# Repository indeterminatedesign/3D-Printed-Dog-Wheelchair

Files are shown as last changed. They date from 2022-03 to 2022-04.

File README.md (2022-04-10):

<h1>3D Printed Dog Wheelchair</h1>
<p>The construction is a bit unrefined given this was a version 1, and as such is not beginner project as it requires intermediate fabrication skills at a minimum. 
Feel free to take this design to the next level for your purposes. </p>
<p>The wheelchair is made from mostly 3d printed parts and uses 1/2" EMT conduit for its main structure. I've tested the wheelchair with a 65lbs dog and found no issues, but obviously your mileage may vary. </p>

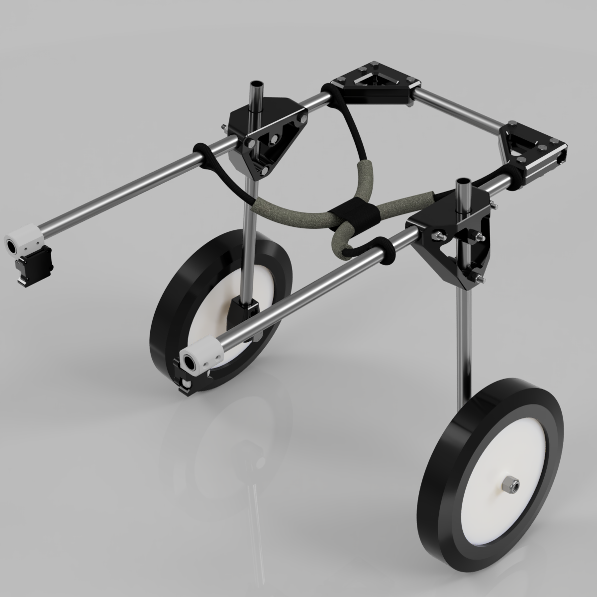
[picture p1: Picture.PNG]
Wheelchair Picture


<h2>Materials List</h2>
<p>You'll of course need a full assortment of the appropriate tools, including wrenches, hacksaw/tubing cutter, drill, drill bits, zip ties, electrical tape, etc.  </p>
<p>Depending on your dog's size it's typically cheaper to buy a single 10' length piece of conduit.  </p>

<p>The 3D printed structure of wheelchair can be printed out of PLA, PLA+ (Highly recommended) or PETG.  I highly recommend PETG or Nylon for the buckles as it is more durable, easier to unbuckle, and holds it shape better than PLA.  The 3D printed parts require roughly 0.8kg of filament.</p>

<p>The wheels I used are cheap 10" cart wheels from Harbor Freight, but any 1/2" diameter axle wheel can be used.  Obviously the larger the diameter the easier the wheelchair can traverse obstacles.</p>

The sling is made from vinyl tubing with a 1/4" ID, (I used some unknown tubing that I already had so this may not be the exact size).  I purchased 10mm ID, EVA foam tube padding from Amazon. 
To create the middle of the sling I use a hiking sock cut in half.  Obviously, this could be improved.</p>
<p>Additionally, you'll need a harness that fits your dog to clamp the buckle brackets to.  This is the harness I used: https://www.amazon.com/tobeDRI-Harness-Adjustable-Reflective-Control/dp/B086PCQ3HQ/?th=1</p>

<h4>Hardware List</h4>
<meta http-equiv="Content-Type" content="text/html; charset=utf-8"><link type="text/css" rel="stylesheet" href="resources/sheet.css" >
<div class="ritz grid-container" dir="ltr"><table class="waffle" cellspacing="0" cellpadding="0"><thead><tr><th class="row-header freezebar-origin-ltr"></th><th id="0C0" style="width:96px;" class="column-headers-background">A</th><th id="0C1" style="width:100px;" class="column-headers-background">B</th><th id="0C2" style="width:40px;" class="column-headers-background">C</th><th id="0C3" style="width:134px;" class="column-headers-background">D</th></tr></thead><tbody><tr style="height: 20px"><th id="0R0" style="height: 20px;" class="row-headers-background"><div class="row-header-wrapper" style="line-height: 20px">1</div></th><td class="s0" dir="ltr">Bolt</td><td class="s0" dir="ltr">Length</td><td class="s0" dir="ltr">Qty.</td><td class="s1 softmerge" dir="ltr"><div class="softmerge-inner" style="width:232px;left:-1px">Optional Metric Size</div></td></tr><tr style="height: 20px"><th id="0R1" style="height: 20px;" class="row-headers-background"><div class="row-header-wrapper" style="line-height: 20px">2</div></th><td class="s2" dir="ltr">1/4-20</td><td class="s2" dir="ltr">1.5&quot;</td><td class="s3" dir="ltr">10</td><td class="s4" dir="ltr">M6x40</td></tr><tr style="height: 20px"><th id="0R2" style="height: 20px;" class="row-headers-background"><div class="row-header-wrapper" style="line-height: 20px">3</div></th><td class="s5" dir="ltr">1/4-20</td><td class="s5" dir="ltr">2&quot;</td><td class="s6" dir="ltr">6</td><td class="s7" dir="ltr">M6x50</td></tr><tr style="height: 20px"><th id="0R3" style="height: 20px;" class="row-headers-background"><div class="row-header-wrapper" style="line-height: 20px">4</div></th><td class="s2" dir="ltr">1/4-20</td><td class="s2" dir="ltr">2.5&quot;</td><td class="s3" dir="ltr">2</td><td class="s4" dir="ltr">M6x65</td></tr><tr style="height: 20px"><th id="0R4" style="height: 20px;" class="row-headers-background"><div class="row-header-wrapper" style="line-height: 20px">5</div></th><td class="s5" dir="ltr">1/4-20 Locnuts</td><td class="s5"></td><td class="s6" dir="ltr">18</td><td class="s7" dir="ltr">M6</td></tr><tr style="height: 20px"><th id="0R5" style="height: 20px;" class="row-headers-background"><div class="row-header-wrapper" style="line-height: 20px">6</div></th><td class="s2" dir="ltr">1/4&quot; Washers</td><td class="s2" dir="ltr"></td><td class="s3" dir="ltr">36</td><td class="s4" dir="ltr">M6</td></tr><tr style="height: 20px"><th id="0R6" style="height: 20px;" class="row-headers-background"><div class="row-header-wrapper" style="line-height: 20px">7</div></th><td class="s5" dir="ltr">1/2&quot;</td><td class="s5" dir="ltr">4.25&quot;-4.5&quot;</td><td class="s6" dir="ltr">2</td><td class="s7" dir="ltr">M13x110</td></tr><tr style="height: 20px"><th id="0R7" style="height: 20px;" class="row-headers-background"><div class="row-header-wrapper" style="line-height: 20px">8</div></th><td class="s2" dir="ltr">1/2&quot; Locnuts</td><td class="s2"></td><td class="s3" dir="ltr">2</td><td class="s4" dir="ltr">M13</td></tr><tr style="height: 20px"><th id="0R8" style="height: 20px;" class="row-headers-background"><div class="row-header-wrapper" style="line-height: 20px">9</div></th><td class="s5" dir="ltr">1/2&quot; Washers</td><td class="s5" dir="ltr"></td><td class="s6" dir="ltr">4</td><td class="s7" dir="ltr">M13</td></tr><tr style="height: 20px"><th id="0R9" style="height: 20px;" class="row-headers-background"><div class="row-header-wrapper" style="line-height: 20px">10</div></th><td class="s2 softmerge" dir="ltr"><div class="softmerge-inner" style="width:93px;left:-1px">#8-32 flat head</div></td><td class="s2" dir="ltr">~5/8&quot;</td><td class="s3" dir="ltr">4</td><td class="s4" dir="ltr">M4x13 flat head</td></tr><tr style="height: 20px"><th id="0R10" style="height: 20px;" class="row-headers-background"><div class="row-header-wrapper" style="line-height: 20px">11</div></th><td class="s5 softmerge" dir="ltr"><div class="softmerge-inner" style="width:93px;left:-1px">#8-32 flat head</div></td><td class="s5" dir="ltr">~1 1/8&quot;</td><td class="s6" dir="ltr">4</td><td class="s7" dir="ltr">M4x30 flat head</td></tr></tbody></table></div>
<i>Note:  Washers are absolutely critical as they help to distribute the load over a larger area.</i>

<h2>Printing Instructions</h2>
<p>Most of the parts can be printed without supports, and I highly recommend doing so.  
The parts that I know require support are the large triangular upper block pieces.</p>
<p> I printed all of my parts with 5 walls and 5 top and bottom layers with 30% infill.   

<h2>Assembly Instructions</h2>
See my YouTube video below.

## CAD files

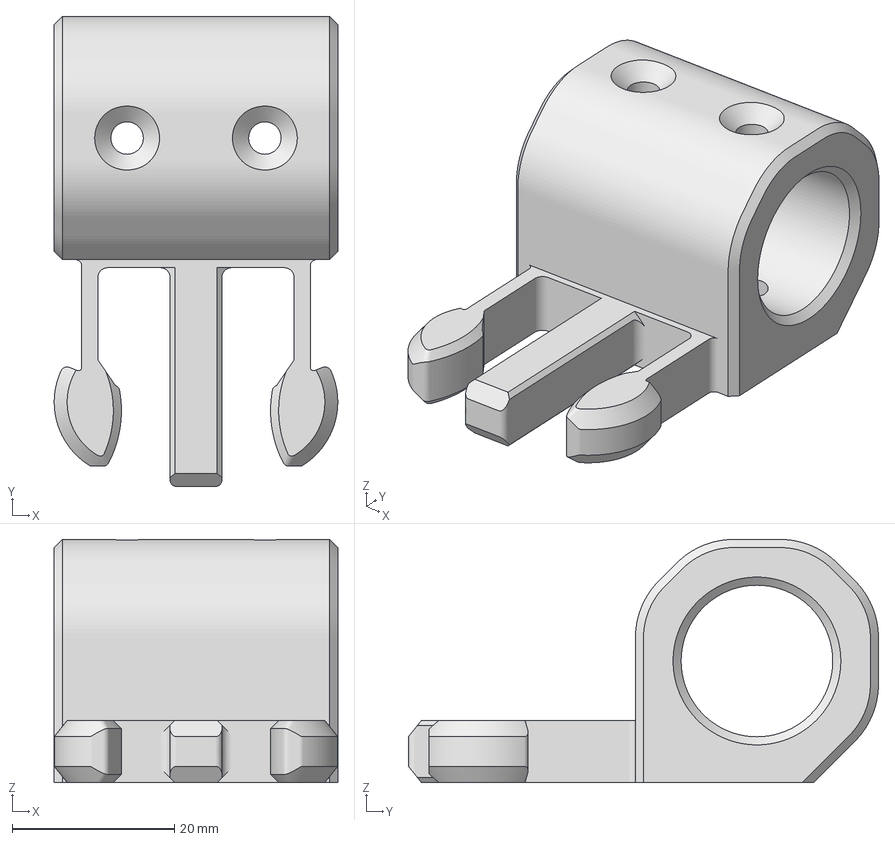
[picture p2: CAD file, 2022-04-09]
3MF Files/Front Buckle Frame Side.3mf
35.0 x 58.0 x 30.0 mm

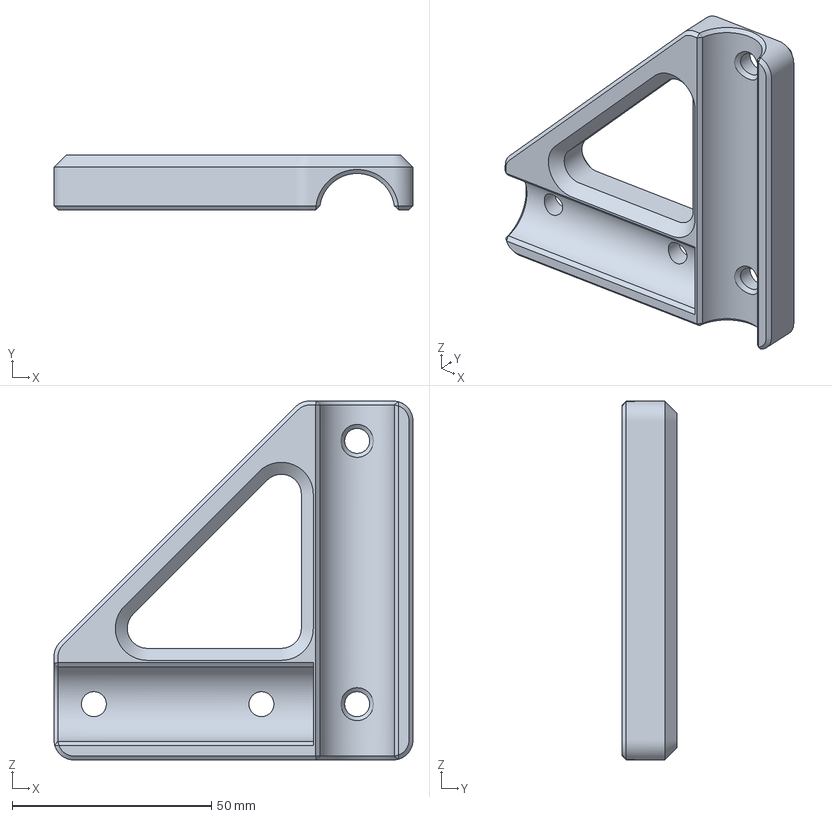
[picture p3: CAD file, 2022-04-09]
3MF Files/2x RightAngle Connector(Mirror).3mf
90.0 x 13.7 x 90.0 mm

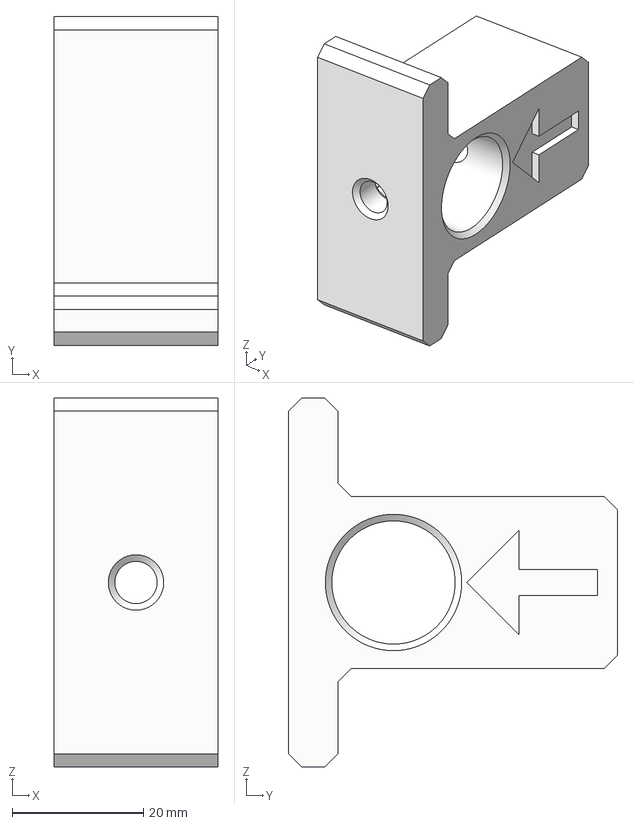
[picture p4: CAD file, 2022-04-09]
3MF Files/HoleDrillJig.3mf
25.0 x 50.2 x 56.3 mm

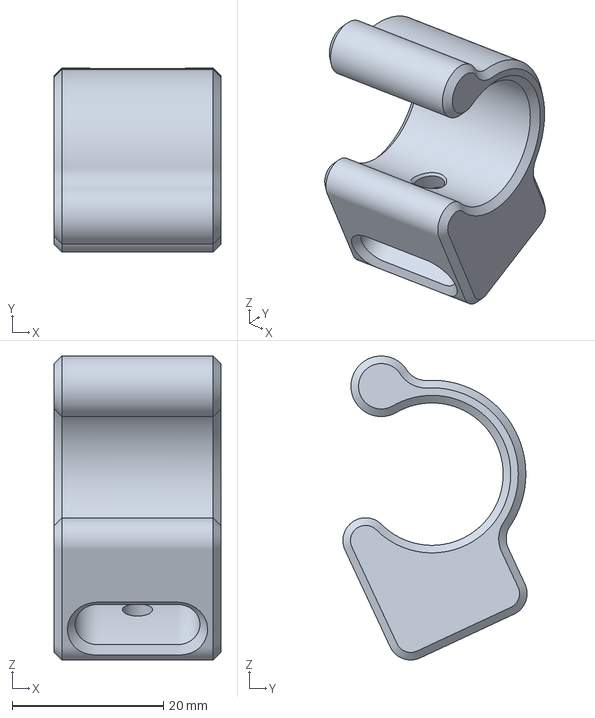
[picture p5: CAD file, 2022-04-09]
3MF Files/Hook.3mf
22.0 x 24.3 x 40.2 mm

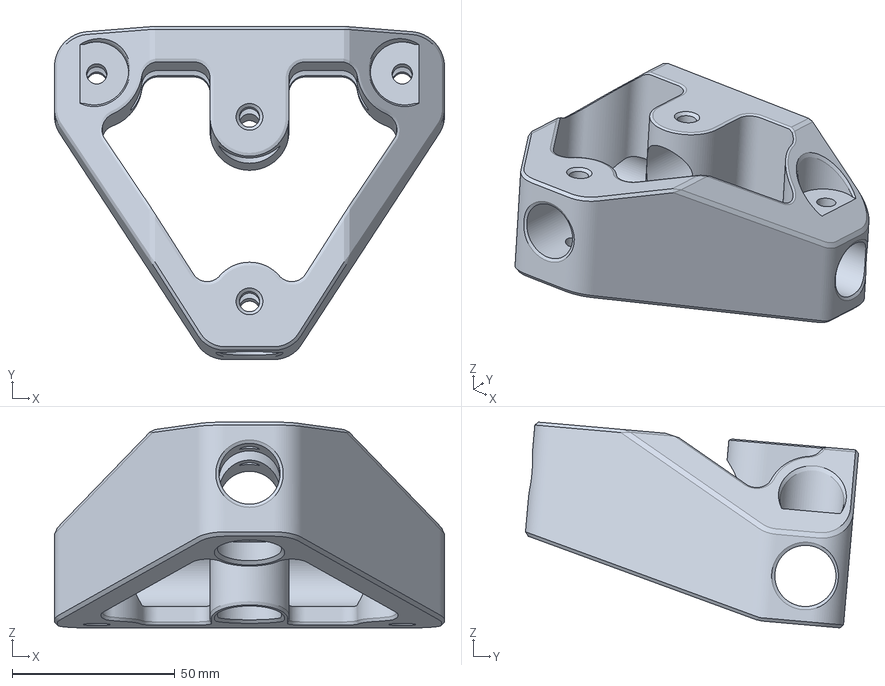
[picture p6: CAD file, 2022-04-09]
3MF Files/Upper Frame Block.3mf
120.0 x 102.5 x 63.3 mm

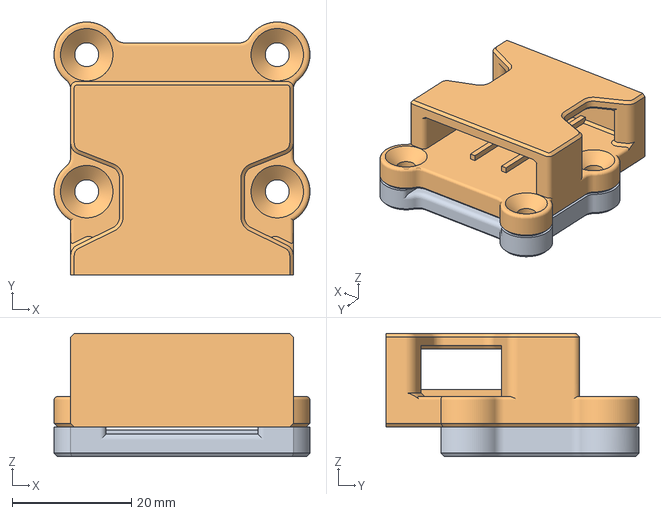
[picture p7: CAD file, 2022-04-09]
3MF Files/FrontBuckleHarnessSide.3mf
43.0 x 42.5 x 20.7 mm
Buck Pt1

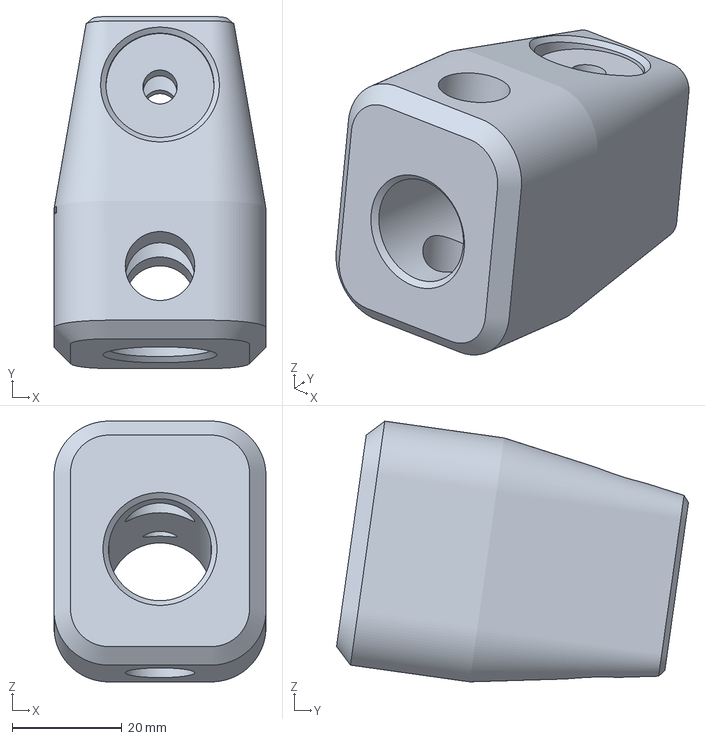
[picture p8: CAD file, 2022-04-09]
3MF Files/WheelBlock.3mf
38.7 x 64.3 x 47.6 mm

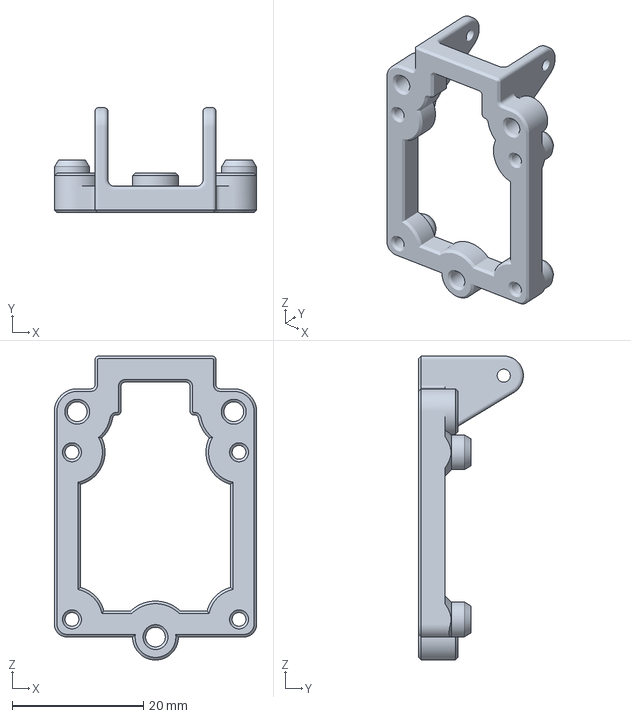
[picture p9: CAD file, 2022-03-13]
3MF Files/Mount.3mf
30.9 x 16.0 x 46.4 mm

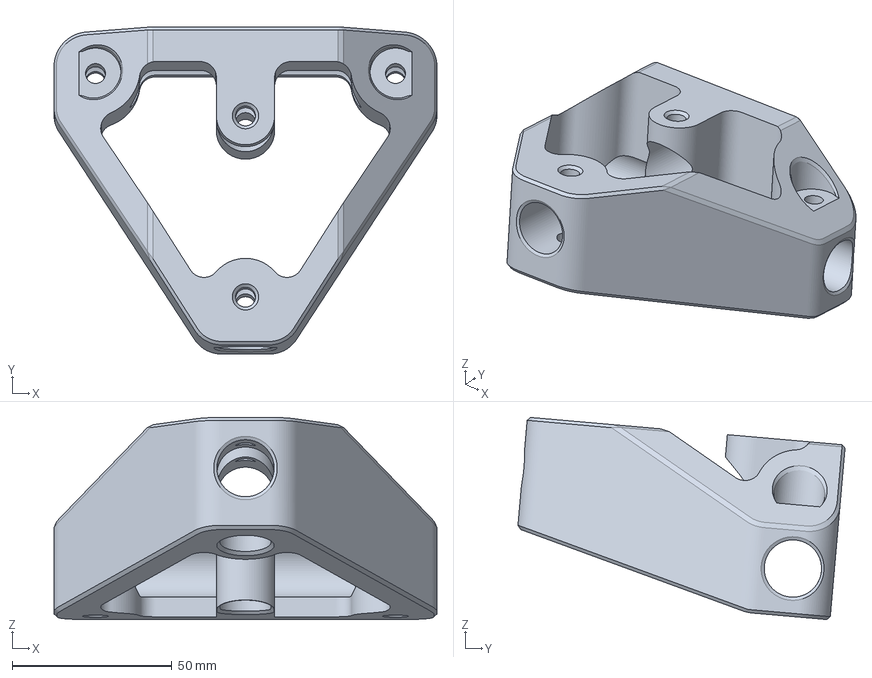
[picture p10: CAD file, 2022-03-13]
3MF Files/Upper Block.3mf
120.0 x 102.5 x 63.3 mm

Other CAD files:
3MF Files/2x RightAngle Connector.3mf

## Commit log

2022-03-13 Initial Commit
    Initial Commit
    [Front Buckle Frame Side.3mf, FrontBuckleHarnessSide.3mf, Mount.3mf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]
2022-04-09 Revised Parts
    [2x RightAngle Connector(Mirror).3mf, 2x RightAngle Connector.3mf, Front Buckle Frame Side.3mf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]
2022-04-09 Adding CAD files
    [Upper Block thinned.3mf]
